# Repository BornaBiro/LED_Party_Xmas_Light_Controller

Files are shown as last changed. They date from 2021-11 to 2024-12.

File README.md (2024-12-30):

# 🎄LED Party And Xmas Light Controller🎄

ATMGEA328P based project for ccontrolling WS2801 RGB LEDs (addressable LEDs with dedicated IC controller, not the ones with built-in controller). It's primarlly used for controlling LED lights for Xmass, but with some code modification can be used for smart ambient light or even a party light (it already has dedicated mode for that, but it does not work properly, more about that later).

<p align="center">
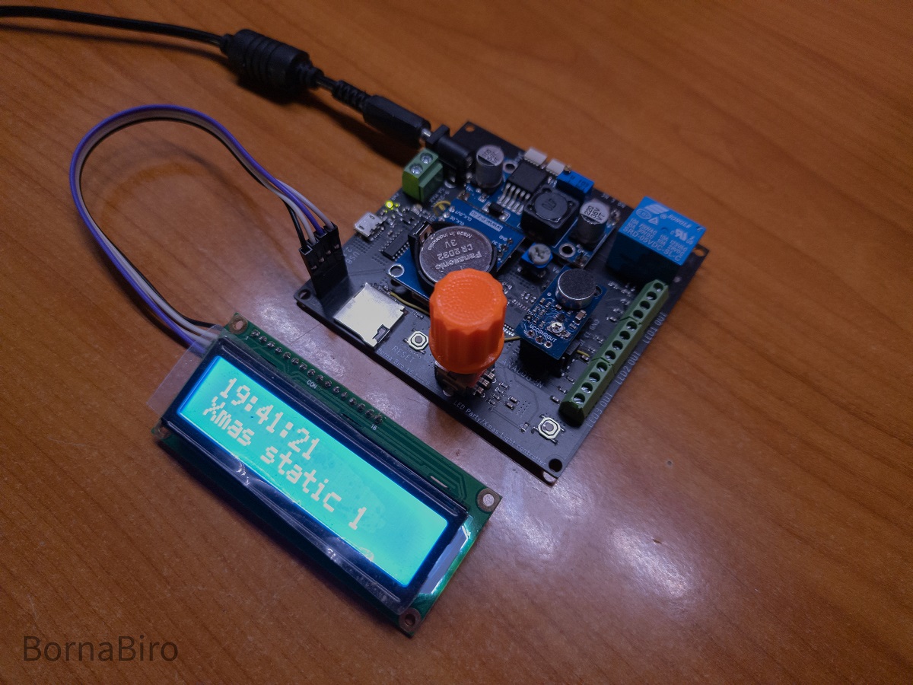
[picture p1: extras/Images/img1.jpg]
  
</p>

<p align="center">
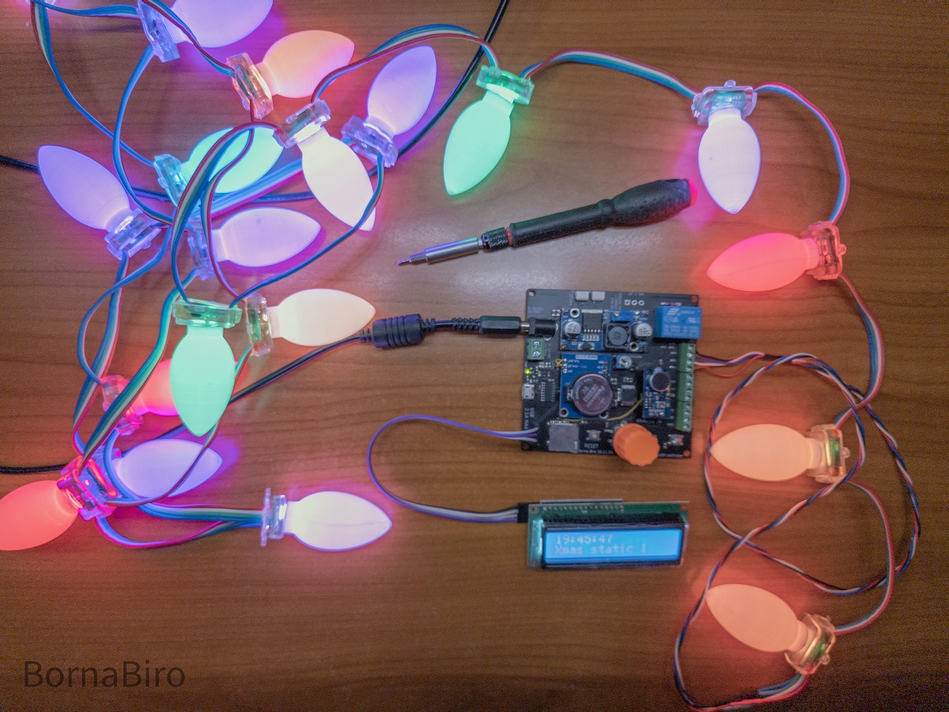
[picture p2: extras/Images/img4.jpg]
  
</p>

## Features 
- microUSB supply
- DC Jack supply (microUSB and DC Jack **CAN'T** be used at the same time!)
- Terminal block for power supply (connected in parallel with DC Jack)
- Analog audio input for MAX4466 microphone breakout
- microSD card reader
- 16x2 I2C LCD
- 2 (3) x LED Channels
- built-in buck regulator for 5V power supply
- RTC for automatic power on and off
- relay output (**for non-mains use only**)
- rotary encoder wuth pushbutton for navigating menu
- buzzer for playing old school Xmas melodies
- CH340 USB to UART IC for easy programming and debugging
- Reset pushbutton
- Addidional pushbutton
- easyC / STEMMA / Qwiic I2C connector for additional I2C devices

There is very neat little feature with this device: it creates same melodies as these old school incandescent Xmas lights. Check that out [here](https://github.com/BornaBiro/LED_Party_Xmas_Light_Controller/blob/dev/Codes/Melody%20Extract/README.md).

## Getting started 🚀
1. Get the board!
2. Get the parts!
3. Solder everything together (except DC-DC converter, **you must set the output voltage to 5V-5.2V first**)
4. Connect DC-DC converter to the power supply and set the output voltage to the 5V-5.2V
5. Solder it to the PCB using the headers
6. Burn the bootloader to the ATMEGA328P (using the test pads at bottom side of the PCB). You can use Arduino as ISP. If you don't know how to use it, check it out [here](https://docs.arduino.cc/built-in-examples/arduino-isp/ArduinoISP).
7. Copy / install provided WS2801 library to the Arduino
8. Open the sketch
9. Set Board as Arduino Nano (Arduino Nano with ATMEPGA328P, old bootloader).
10. Upload the sketch
11. Have fun!

## Contributions to this project
- [ladyM9](https://github.com/ladyM9) - Little help for the timer code (got few ideas on how to approach the problem). Thank you!
- [keith204](https://www.thingiverse.com/keith204/designs) 3D Printed caps for the LEDs - https://www.thingiverse.com/thing:3331268

## Hadrware issues
⚠️**NOTE**⚠️

Before making the CB you have to know that current version of the PCB has _some_ hardware issues. All issues are listed [here](https://github.com/BornaBiro/LED_Party_Xmas_Light_Controller/tree/dev/PCB#hadrware-issues).

⚠️**NOTE**⚠️

I **did not** fix any of these on PCB design, so like I mentioned, you will either need to do these fixes or you will need to make changes on the PCB before you order it.

## Software issues
Software is still in the progress of make it. Since I do not have much free time, do not have high hopes on fixing these. I'll try my best to fix these before Xmas and New Year.
Whole code is written to be non-blocking.

Known issues:
1. Xmas mode and Party Mode are not seperated. Actually on new and updated version only Xmas mode exists!
2. Only xmas mode is working properly
3. Be careful while setting up current Xmas mode, because you can force it into party mode by incrementing it to the Moon and beyond. Not sure if this is a bug or feature. 😆
4. No day selecton on automatic on or off (no date setting either)
5. 3D printed case is still missing.
6. For longer strands with total number of LEDs > 40 one Step Down is not enough.

## To-Do list
1. Try create two different flash images fir different modes that can be loaded into ATMEGA328P from the microSD card
2. Variable/Selectable length of LEDs per output
3. Enable or disable some effects or put them in the list
4. More effects!
5. More timer intervals
6. UART control support

## How to use it
The device has two/three WS2802 LEDs outputs. Number of LEDs per output can be configured in the [code](Codes/Arduino%20Code/led_party_xmas_light_controller/defines.h), STRAND1, STRAND2 and STRAND3. Third channel can be used for relay output (selected by default) or for one more channel for LEDs. On first start up it will set all setting to default ones. Every settting is stored in ATMEGA328P EEPROM. To enter menu, press Rotary Enc. To go thorugh menu, rotate rotary encoder. To enter settings, press the encoder again. Rotate it to set parameters. To go on the next parameter press the encoder. To exit setting, wait or simply keep pressing until `>` is not visable anymore. `>` shows what parametes is currently being set. To exit menu, wait or go to `Exit`. The menu will timeout as well as the backlight.

### Menu
  - Current mode: Shows current mode - Only Xmas for now
  - Current setting: Shows what light mode is currently active (same on the main menu along with the clock)
  - Frame speed: To slow or speed up the current animation (in percent)
  - Animation dur.: How long to keep current light effect (in seconds)
  - Auto Change: If enabled it will go though all light modes automatically.
  - Melody: If enabled it will play the melody if light mode has melody.
  - Auto Start: If set on `Auto`, light will power up automaticaly accordingly on `Activation Time` intervals. Relay and LEDs are seperated. `On` will keeps LEDs or relay on all the time overriding timer intervals.
  - Set Time: Set the time on RTC.
  - Activation Time: Set the times when the device will be powered on. First time is when device will be enabled, second is when the deivce disable LEDs/Relay. Y/N is if this timeslot it even enabled or not.
  - Exit: Exit menu.

## Few more images

<p align="center">
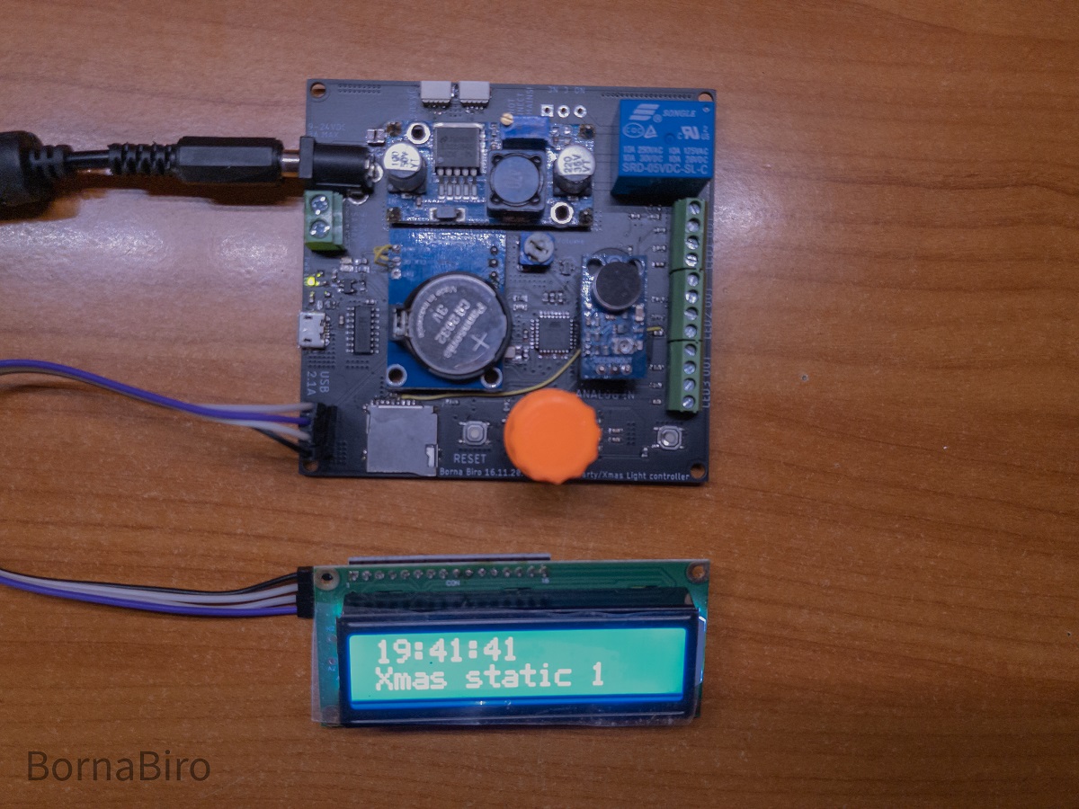
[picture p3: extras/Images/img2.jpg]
  
</p>

<p align="center">
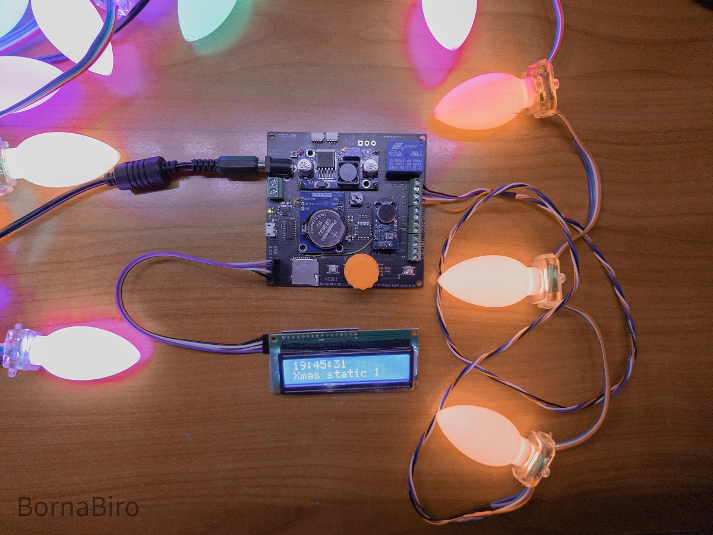
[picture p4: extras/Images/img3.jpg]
  
</p>

## Licence
This project uses MIT licence. It is provided as is - no warranty is given. In other words - use it at your own risk.
You can use this project, change it, modify it, but source must be listed (this github repo) as well as the author name.

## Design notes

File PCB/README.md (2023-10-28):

PCB CAD files are made with EAGLE. I will add gerbers files later (if needed).

### Hadrware issues
Yeah, this things happen, it doesn't work from the first try, so there are some fixes you need to make in order to your PCB work properly.

1. microUSB connector does not fit. I use wrong footprint. Used microUSB connector is [920-E52A2021S10100](https://www.lcsc.com/product-detail/USB-Connectors_Jing-Extension-of-the-Electronic-Co-920-E52A2021S10100_C10418.html)
2. Missing SMD 10uF MLCC at DC input
<p align="center">
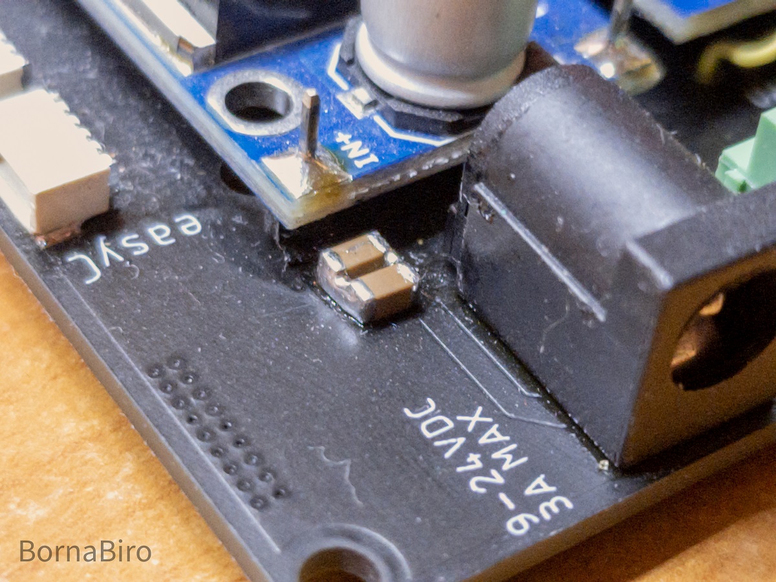
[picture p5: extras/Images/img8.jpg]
  
</p>
3. Missing debounce capacitor on rotary enncoder pushbutton from pin to GND (100nF)
<p align="center">
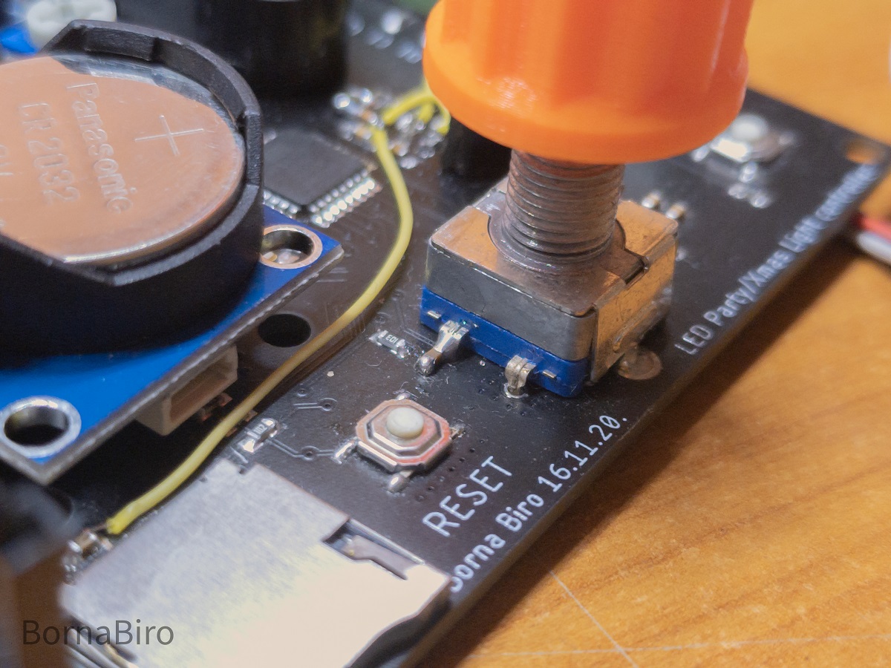
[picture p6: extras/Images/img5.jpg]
  
</p>
4. Analog audio part... Ohh boy... AVCC and AREF sholud be seperated (AVCC should be on 5V but AREF should be on 3V3), bias curcuit is missing filtering, MIC and bias must be supplied from 3V3.
<p align="center">
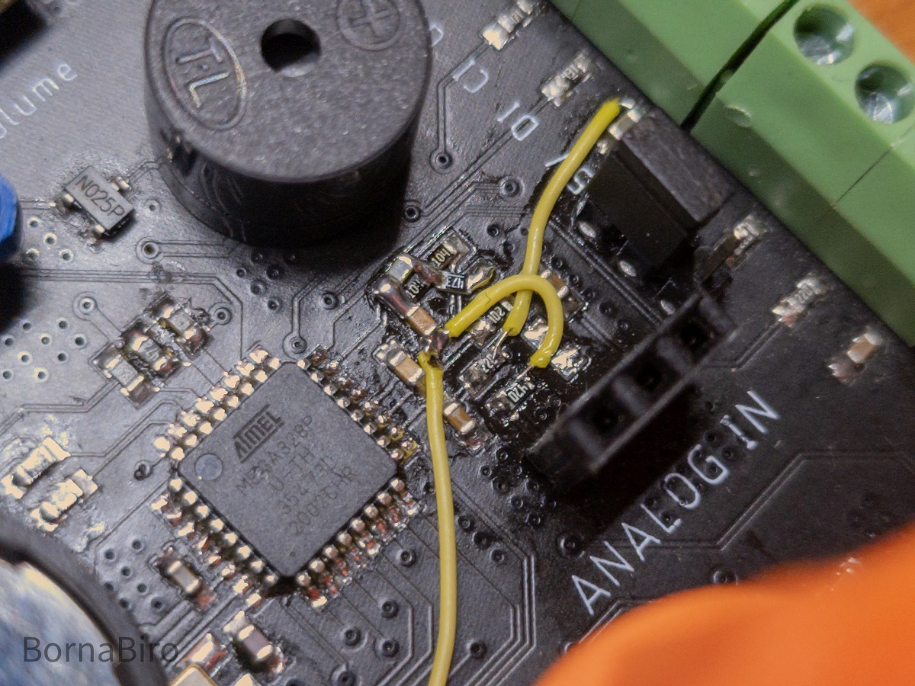
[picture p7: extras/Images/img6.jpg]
  
</p>
5. No GND at 3V3 VREG... This one hurts the most...
<p align="center">
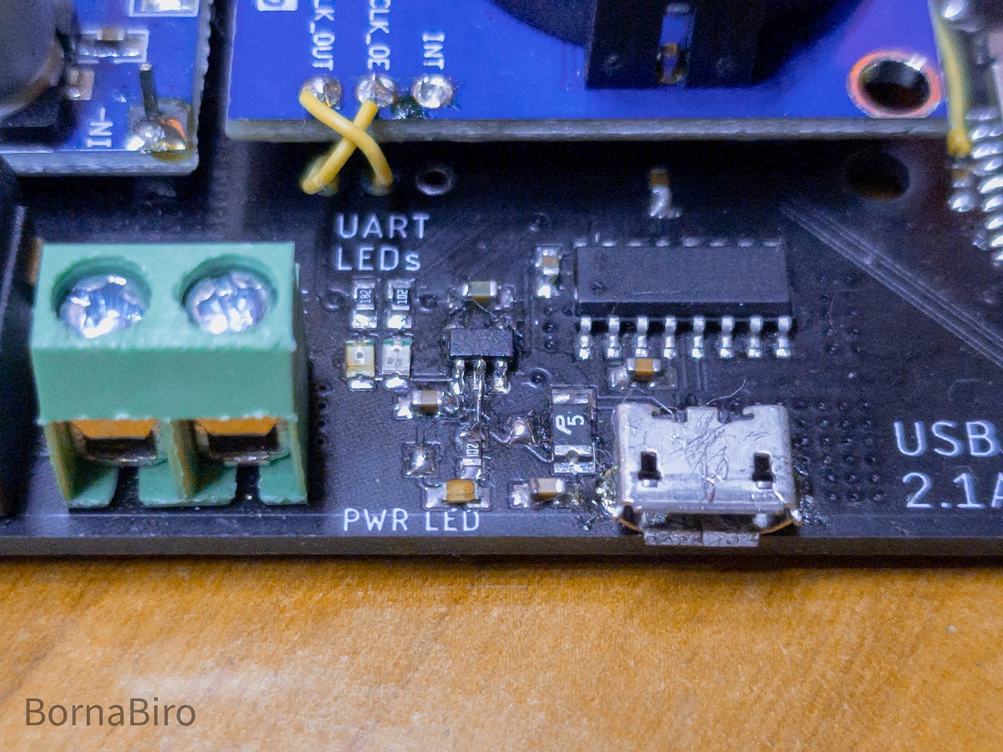
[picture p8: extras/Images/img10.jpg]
  
</p>
6. Swapped CLK_OUT and CLK_OE... and this one...
<p align="center">
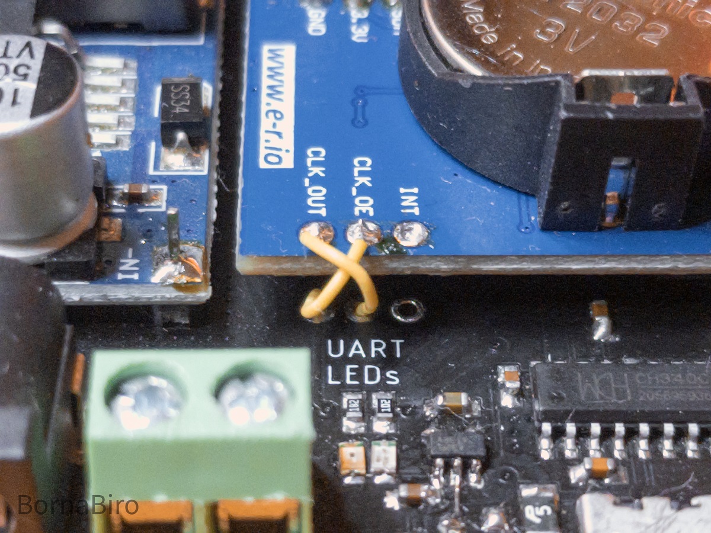
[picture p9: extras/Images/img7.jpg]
  
</p>
7. In order to make MIC breakout to work properly (so it does not capture noise from the power supply), cut the MIC supply trace and add 10uF 1206 MLCC.
<p align="center">
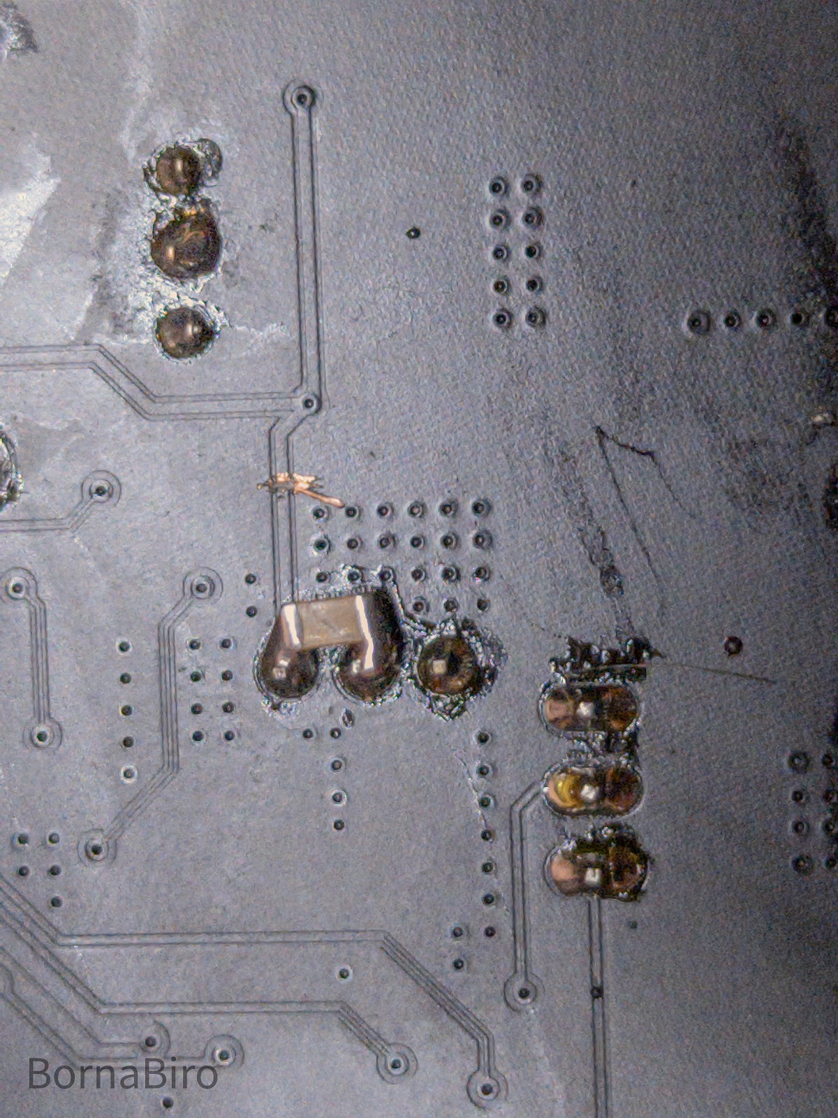
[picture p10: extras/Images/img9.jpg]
  
</p>
8. Added two 1206 10uF MLCC at the output of the DC-DC converter to reduce high frequency noise.
<p align="center">
  
</p>
9. Some of these DC-DC converters are noisy. If needed, add 470uF at the output of the DC-DC converter.

**NOTE** I did not fix any of these on PCB design, so like I mentioned, you will either need to do these fixes or you will need to make changes on the PCB before you order it.

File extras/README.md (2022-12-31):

NOTE: All there songs are extracted from old filament lamp type X-mas lights controller box. I have no idea if they are copyrighted or not, so use it only for educational, demostrantional and non-commertional use only!

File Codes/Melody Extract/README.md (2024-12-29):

# Code for melody extraction from old school Xmas light "automata"

## Intro
Remeber these things? We use to hate it back in the days with it's irritating melodies they produced. But nowdays I really miss these melodies. Maybe I'm little bit nostalgic ... or crazy, who knows. :D 
<p align="left">
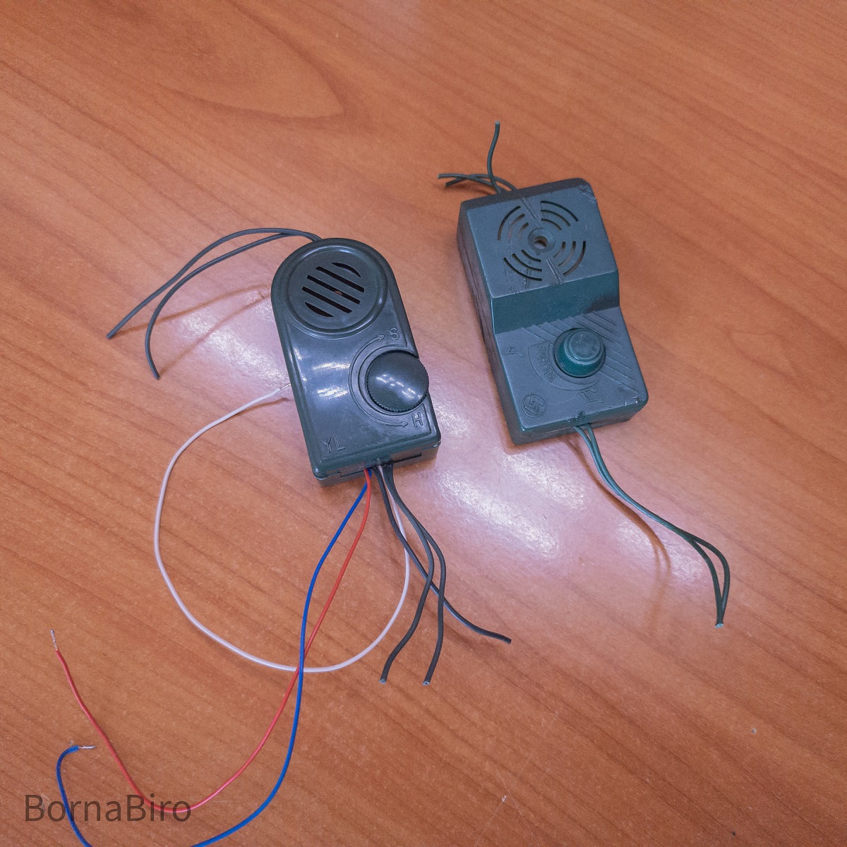
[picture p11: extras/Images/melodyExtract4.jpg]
  
</p>

I wanted to add melodies from these little noise makers, but I colud not found them anywhere on the web in the form of the notes and their durations in miliseconds.
I could find the songs and then manually convert them into notes (and frequencies) and durations, but this takes way too much time.
Or I could use these two and record the sound the produce into .wav file, store it on the microSD card and reproduce it with ATMEGA328P, but that would use way too much memory and CPU cycles.
But I needed much simpler solution. I got an idea. What if I record the signal comming from the IC inside this automata and use that?

But how? Well, here is how I done it. By using cheap 24MHz logic analyzer and some C code, of course!
<p align="left">
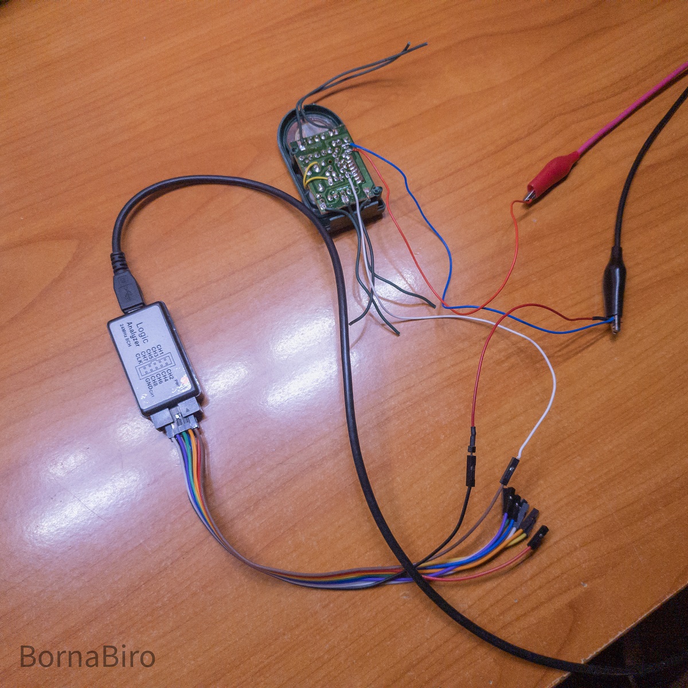
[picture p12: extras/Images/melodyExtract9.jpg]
  
</p>

You could use alerady extracted files (provided here as [newerAutomata.csv](https://raw.githubusercontent.com/BornaBiro/LED_Party_Xmas_Light_Controller/dev/Codes/Melody%20Extract/newerAutomata.csv) and [oldestAutomata.csv](https://raw.githubusercontent.com/BornaBiro/LED_Party_Xmas_Light_Controller/dev/Codes/Melody%20Extract/oldestAutomata.csv)) or even cleaned up file [here](https://raw.githubusercontent.com/BornaBiro/LED_Party_Xmas_Light_Controller/main/extras/xmas_light_automata_songs.txt).
But, if you are having one with the different set of melodies, join me on this adventure.

## Hardware side of things
First question that you may ask yourself can be "How do I connect logic analyzer to that?!" and that would be great a question. First thing to note that, what ever you do

> :warning: **DO NOT CONNECTED THEM INTO MAINS WHILE DOING ANYTHING RELATED TO THIS, PLEASE!!!**.

The truth is, these little devices run on about 3-5VDC. There is simple resistive dropper circuit that will convert 230VAC (or 120VAC) to 3-5V needed IC inside this box to create the melody.
So, for the supply, we need lab. power supply set to 3V with current limit set to no more than 30mA. But, again, where to connect this supply?!?! Calm down, it's actually very easy, just find electrolitic capacitor rated at 16V.
Usually this is the main filter capacitor. Just be careful about the polarity. If there is two caps, one is usually for the main filtering and other one is for speaker. How to know which is which is *fairly easy*; on capacitor, both legs are connected to the main IC, the one for the speaker can only hove one connected to the IC or even none (if the device has transistor ampplifier circuit).

<p align="left">
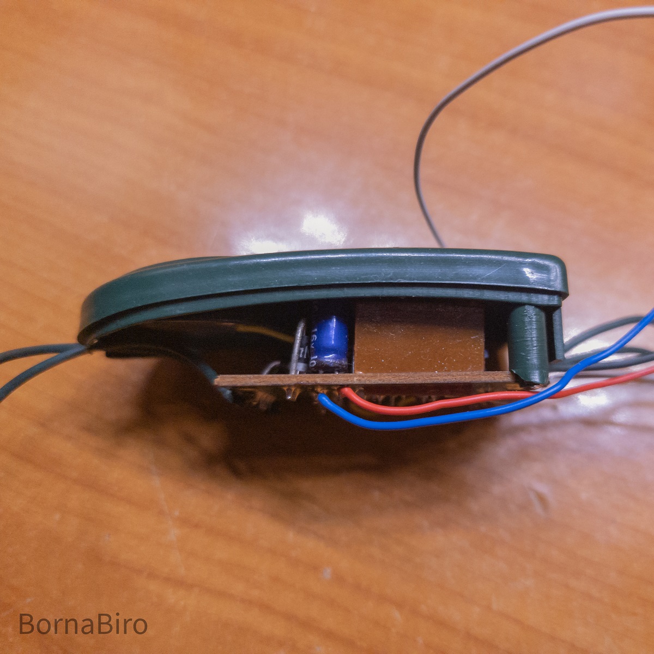
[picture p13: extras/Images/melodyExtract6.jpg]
  
</p>

Now, if you connect the supply, this little noisemaker should start producing sound. If not, either is dead or you connected it wrong. In this case, check the supply current - if needs more than 30mA check the polarity or it's wrong capacitor.

Ok, ok, but where do I connect logic analyzer? Easy there! Fisrt, you will need an oscilloscope. And this does not to be fancy one. Even kit oscilloscopres can be used for this. But for what? Well, we need to find the output pin that goes into speaker to be able to capture the signal.
To find it, power the this noisemaker (**AGAIN NOT FROM THE MAINS, BUT FROM THE LAB. POWER SUPPLY WITH 3-5VDC!**) and try to find pin that produces squarewave with the frequency of about 500Hz to 2kHz. Thats your melody! To be sure, you can attach a small speaker (like a headphones) to check if this is really a signal that we are looking for.

<p align="left">
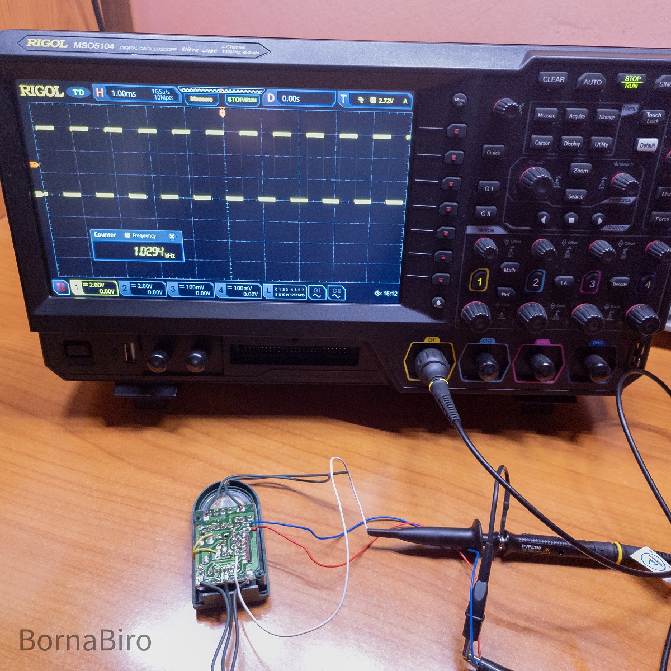
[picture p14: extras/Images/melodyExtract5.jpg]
  
</p>

I already soldered white wire to it (and again, **black nad red wires are 4VDC!**).

Here is the otherone where I'm probing it with the oscilloscope.

<p align="left">
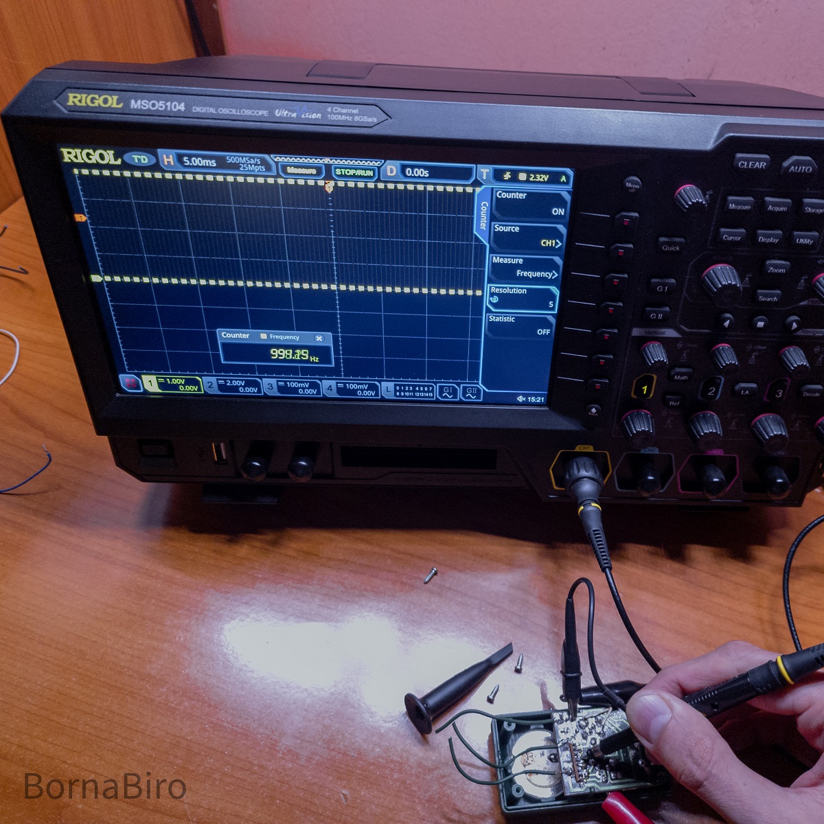
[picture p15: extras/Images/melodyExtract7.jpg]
  
</p>

Close-up shot.

<p align="left">
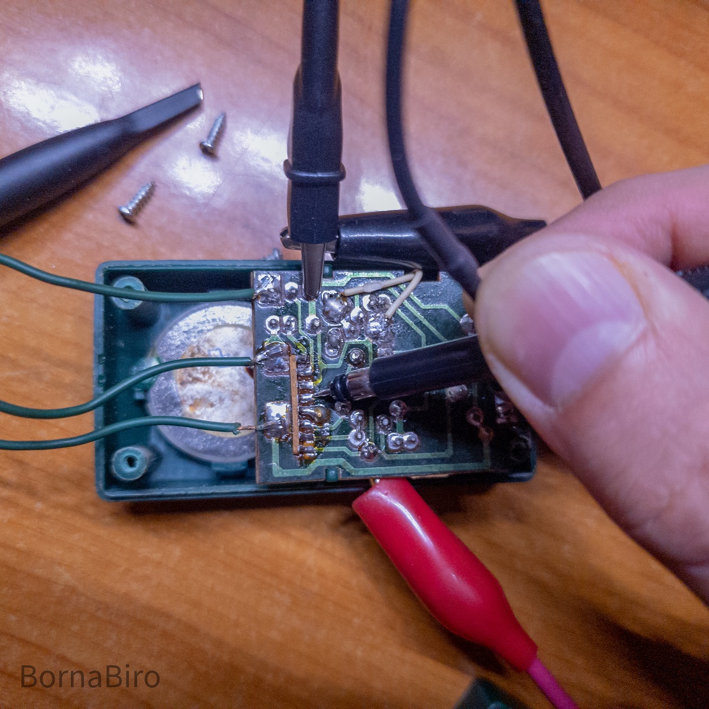
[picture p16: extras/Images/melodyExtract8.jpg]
  
</p>

As you can se this pin generates signal with 50% duty and the frequency is chaning with the sound. That's our signal! Now, solder the wire and connect it to the CH0 of the logic analyzer.

## Software side of things
Ok, now we have the signal, but how to convert that into something useful. Yea sure we can do this manually (please don't) by recording a video and than writing down frequrncies and duration seen on oscilloscope or recording a melody and setting a scopoe on slow time base and by using cursors extract frequency and duration. Or capture everything with the logic analyzer and then manually analyze frequencies and their durations. But this won't be a *engineering* method right? Besides, where is fun in that?
It's much better to write the code that will extract these values. So I did exactly that! Script can be found [here](main.cpp). The code is written in C/C++. I run it by using [DevCpp](https://www.bloodshed.net) but you can run it with simple GCC Compiler.
Code is ment to parse Salea Logic 2 .csv output with all 8 channels active.

<p align="left">
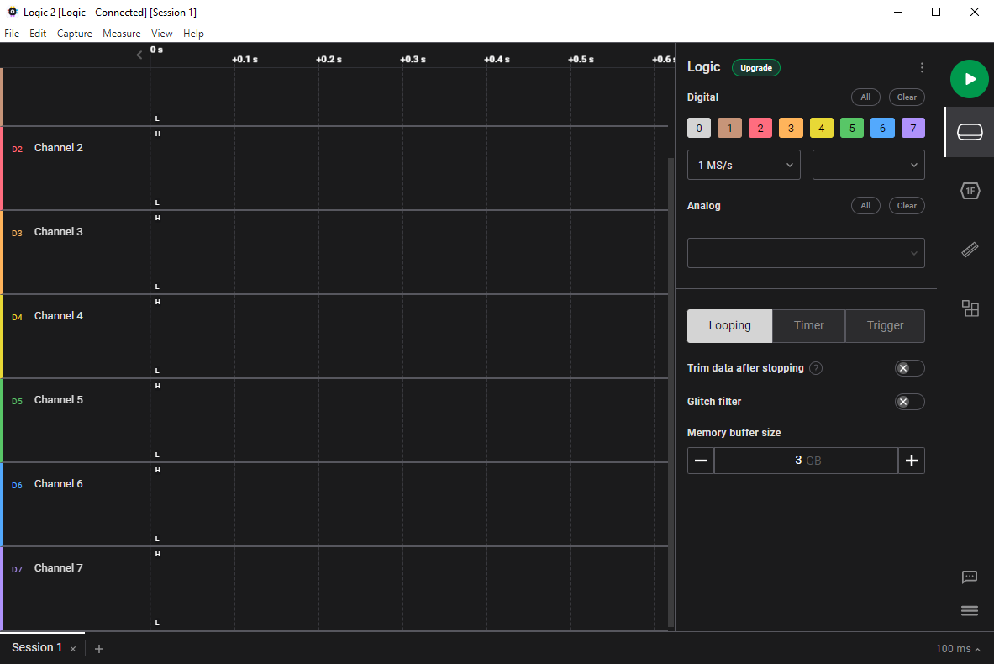
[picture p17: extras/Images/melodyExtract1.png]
  
</p>

Captured data template:
```
Time [s],Channel 0,Channel 1,Channel 2,Channel 3,Channel 4,Channel 5,Channel 6,Channel 7
```

Example of one data point.
```
0.000000000,1,1,1,1,1,1,1,1
```

For script to work properly, use only channel 0 of the logic analyzer!
For export data use this settings:
<p align="left">
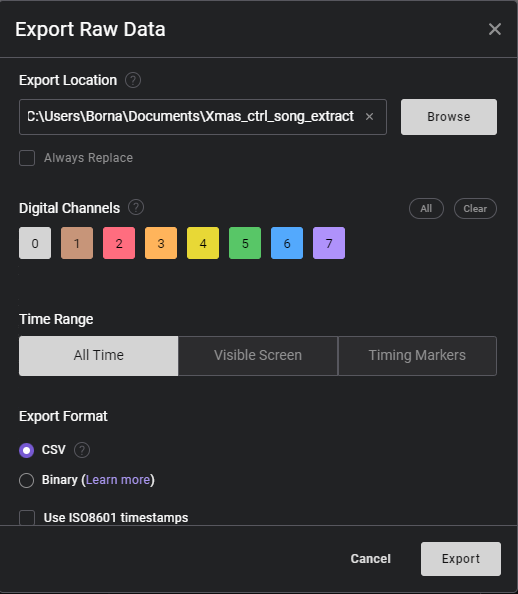
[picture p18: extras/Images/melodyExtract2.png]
  
</p>

You can use [songData.csv](songData.csv) as filename, or you can use whatever name you want as long as you change it in [main.cpp](main.cpp). After running script, you will get [output.csv](output.csv) with frequencies in Hz (Hertz) on the left and durations in milliseconds on the right.

<p align="center">
  
</p>

What the script actually doing is carefully analyzing data and watches for the pin state change and when this happens it captures time from the input time data and calculates the frequency. If frequency is changed from prevoius calculated one (plus tollerance) it save is to the file and also calculates the duration. If not it keeps reading the file until the file is read completly. Now you can use this with any MCU (in my case Arduino and ATMEGA328P).

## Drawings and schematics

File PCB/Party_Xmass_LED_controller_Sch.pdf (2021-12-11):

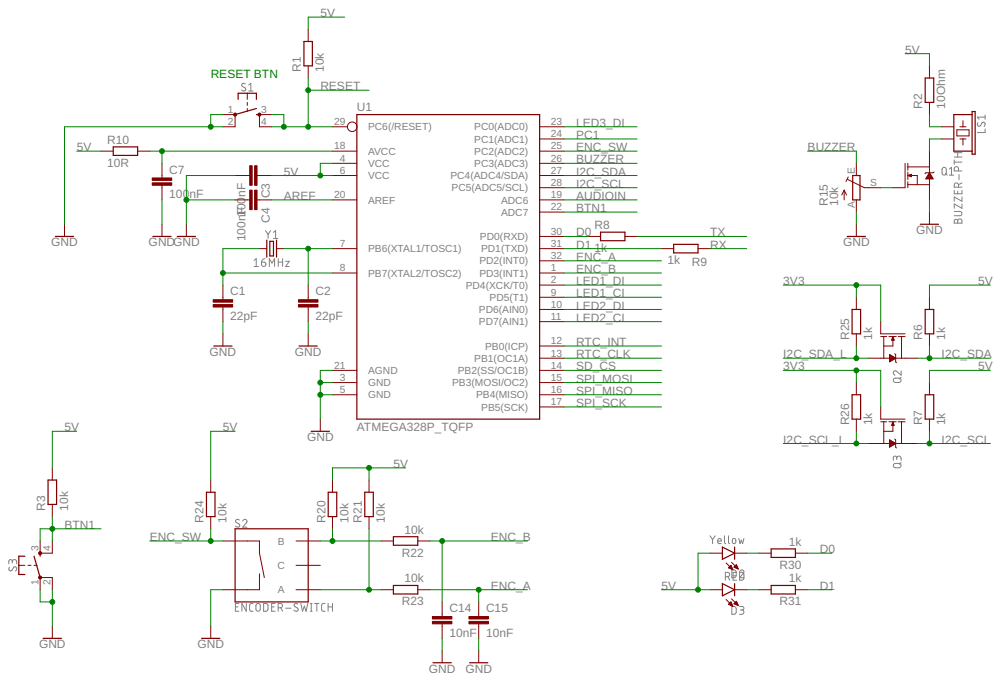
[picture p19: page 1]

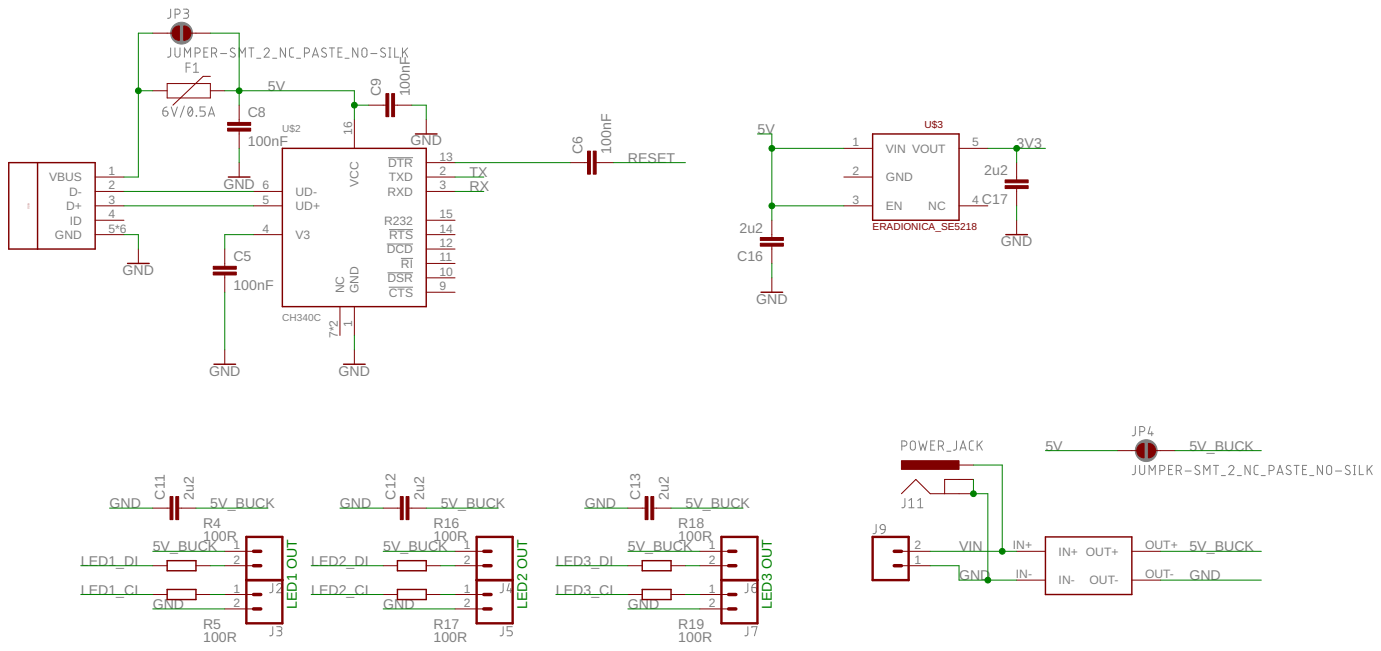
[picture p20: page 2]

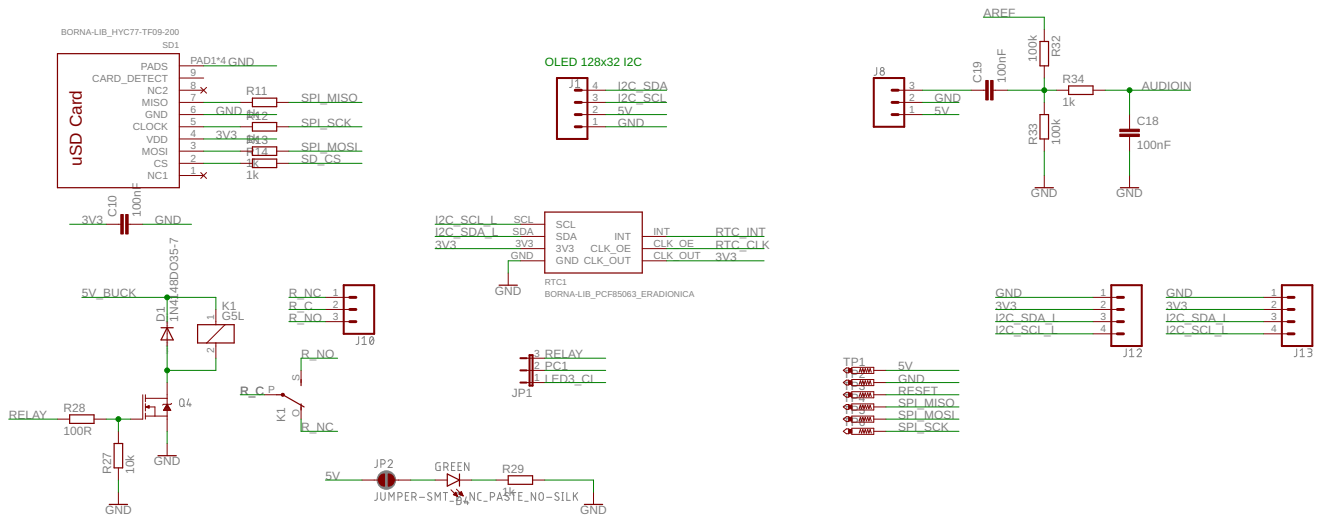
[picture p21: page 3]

SpiceOrder 1 SpiceOrder 2 BORNA-LIB_HYC77-TF09-200 1k1k1k1k 100nF GND BORNA-LIB_PCF85063_ERADIONICA 1G5L N4148DO35-7 GND 10k GND 100R 1k GND 100k 100k 1k 100nF 100nF GND GND CARD_DETECT 9 CLOCK 5 CS 2 GND 6 MISO 7 MOSI 3 NC1 1 NC2 8 PADS PAD1*4 VDD 4 SD1 R11 R12 R13 R14 C10 1234 3V3 3V3 CLK_OE CLK_OE CLK_OUT CLK_OUT GND GND INT INT SCL SCL SDA SDA RTC1 2 1 K1 O S P K1 D1 R27 R28 123 JP1 R29 R32 R33 R34 C18 123 C19 123 TP1 TP2 TP3 TP4 TP5 TP6 1234 1234 GNDGND GND GND GND GND GND GND SPI_MISO SPI_MISO SPI_SCK SPI_SCK SPI_MOSI SPI_MOSI SD_CS 3V3 3V3 3V3 3V3 3V3 3V3 RTC_INT RTC_CLK I2C_SDA_L I2C_SDA_L I2C_SDA_L I2C_SCL_L I2C_SCL_L I2C_SCL_L I2C_SDA I2C_SCL 5V 5V 5V 5V RELAY RELAY LED3_CI PC1 AUDIOIN AREF R_C R_CR_NO R_NO R_NC R_NC RESET 5V_BUCK uSD Card OLED 128x32 I2C

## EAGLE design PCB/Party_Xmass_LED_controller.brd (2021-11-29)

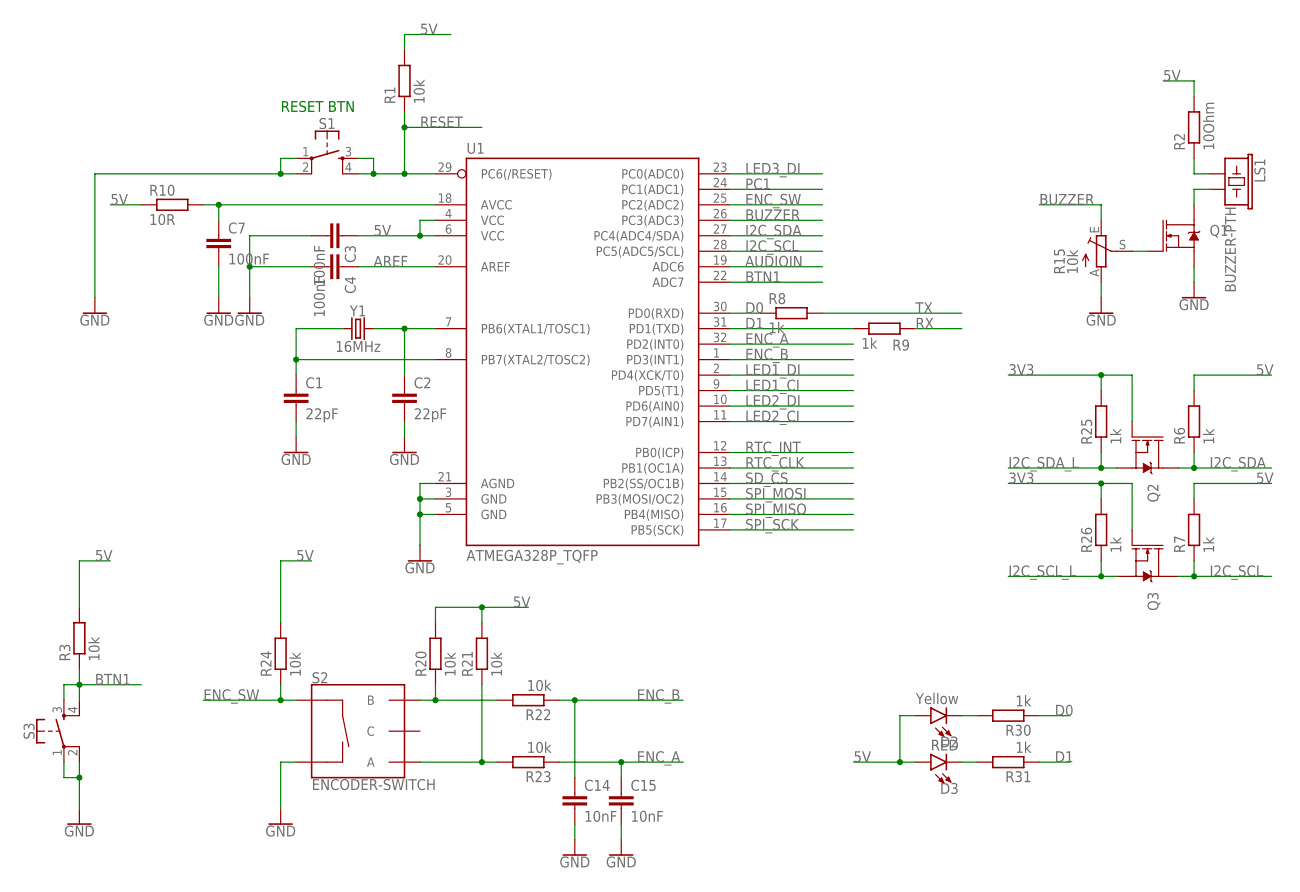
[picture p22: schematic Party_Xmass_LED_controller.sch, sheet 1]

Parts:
C1, C2: 22pF; C0603
C3, C4, C7: 100nF; C0603
C14, C15: 10nF; C0603
D2: Yellow; LED-0603
D3: RED; LED-0603
LS1: BUZZER-PTH; BUZZER-12MM
Q1, Q2, Q3: MOSFET-NCH-BSS138; SOT23-3
R1, R3, R20, R21, R22, R23, R24: 10k; R0603
R2: 10Ohm; R0603
R6, R7, R8, R9, R25, R26, R30, R31: 1k; R0603
R10: 10R; R0603
R15: 10k; CA6V
S1, S3: MOMENTARY-SWITCH-SPST-2-SMD-5.2MM; TACTILE_SWITCH_SMD_5.2MM
S2: ENCODER-SWITCH; ROTARY_ENC_PLAIN
U1: ATMEGA328P_TQFP; TQFP32-08
Y1: 16MHz; CRYSTAL-SMD-5X3.2-4PAD

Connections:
3V3: Q2.1 (G), Q3.1 (G), R25.2, R26.2; also elsewhere on the board
5V: C3.1, D2.A, D3.A, R1.2, R2.2, R3.2, R6.2, R7.2, R10.1, R20.2, R21.2, R24.2, U1.4 (VCC), U1.6 (VCC); also elsewhere on the board
AREF: C4.1, U1.20 (AREF); also elsewhere on the board
AUDIOIN: U1.19 (ADC6); also elsewhere on the board
BTN1: R3.1, S3.3, S3.4, U1.22 (ADC7)
BUZZER: R15.E, U1.26 (PC3(ADC3))
D0: R8.1, R30.1, U1.30 (PD0(RXD))
D1: R9.1, R31.1, U1.31 (PD1(TXD))
ENC_A: C15.1, R23.1, U1.32 (PD2(INT0))
ENC_B: C14.1, R22.1, U1.1 (PD3(INT1))
ENC_SW: R24.1, S2.SW+, U1.25 (PC2(ADC2))
GND: C1.2, C2.2, C3.2, C4.2, C7.2, C14.2, C15.2, Q1.2 (S), R15.A, S1.1, S1.2, S2.SW-, S3.1, S3.2, U1.3 (GND), U1.5 (GND), U1.21 (AGND); also elsewhere on the board
I2C_SCL: Q3.3 (D), R7.1, U1.28 (PC5(ADC5/SCL)); also elsewhere on the board
I2C_SCL_L: Q3.2 (S), R26.1; also elsewhere on the board
I2C_SDA: Q2.3 (D), R6.1, U1.27 (PC4(ADC4/SDA)); also elsewhere on the board
I2C_SDA_L: Q2.2 (S), R25.1; also elsewhere on the board
LED1_CI: U1.9 (PD5(T1)); also elsewhere on the board
LED1_DI: U1.2 (PD4(XCK/T0)); also elsewhere on the board
LED2_CI: U1.11 (PD7(AIN1)); also elsewhere on the board
LED2_DI: U1.10 (PD6(AIN0)); also elsewhere on the board
LED3_DI: U1.23 (PC0(ADC0)); also elsewhere on the board
unnamed: R20.1, R22.2, S2.B
unnamed: LS1.- (2), Q1.3 (D)
unnamed: LS1.+ (1), R2.1
unnamed: C2.1, U1.7 (PB6(XTAL1/TOSC1)), Y1.3 (2)
unnamed: C1.1, U1.8 (PB7(XTAL2/TOSC2)), Y1.1
unnamed: C7.1, R10.2, U1.18 (AVCC)
unnamed: R21.1, R23.2, S2.A
unnamed: Q1.1 (G), R15.S
unnamed: D2.C, R30.2
unnamed: D3.C, R31.2
PC1: U1.24 (PC1(ADC1)); also elsewhere on the board
RESET: R1.1, S1.3, S1.4, U1.29 (PC6(/RESET)); also elsewhere on the board
RTC_CLK: U1.13 (PB1(OC1A)); also elsewhere on the board
RTC_INT: U1.12 (PB0(ICP)); also elsewhere on the board
RX: R9.2; also elsewhere on the board
SD_CS: U1.14 (PB2(SS/OC1B)); also elsewhere on the board
SPI_MISO: U1.16 (PB4(MISO)); also elsewhere on the board
SPI_MOSI: U1.15 (PB3(MOSI/OC2)); also elsewhere on the board
SPI_SCK: U1.17 (PB5(SCK)); also elsewhere on the board
TX: R8.2; also elsewhere on the board

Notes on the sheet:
RESET BTN

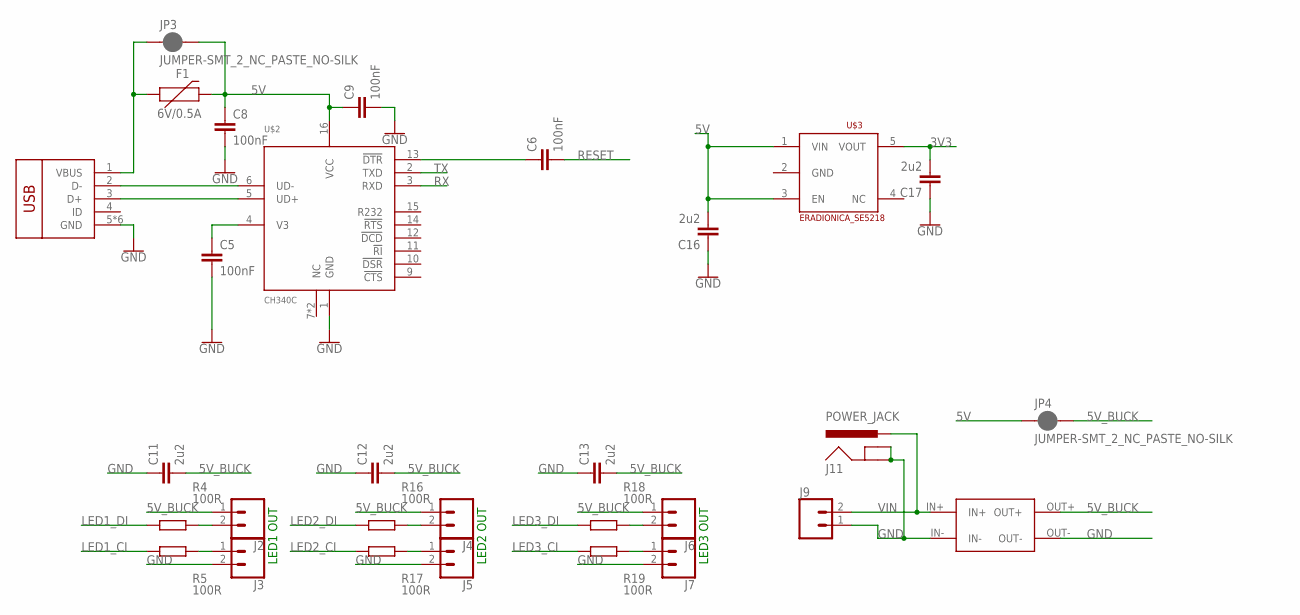
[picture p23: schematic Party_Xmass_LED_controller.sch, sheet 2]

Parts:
C5, C6, C8, C9: 100nF; C0603
C11, C12, C13, C16, C17: 2u2; C0603
F1: 6V/0.5A; 1206
J2, J3, J4, J5, J6, J7: CONN_023.5MM; SCREWTERMINAL-3.5MM-2
J9: CONN_025MM; SCREWTERMINAL-5MM-2
J11: POWER_JACK; POWER_JACK_PTH
JP3, JP4: JUMPER-SMT_2_NC_PASTE_NO-SILK; SMT-JUMPER_2_NC_PASTE_NO-SILK
R4, R5, R16, R17, R18, R19: 100R; R0603
U$1: ERADIONICA_USB-MICRO; ERADIONICA_U-F-M5DD-Y-L
U$2: CH340C; SOP-16
U$3: ERADIONICA_SE5218; ERADIONICA_SOT23-5
U$4: STEPDOWN_MODULE_LM2596

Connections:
3V3: C17.2, U$3.5 (VOUT); also elsewhere on the board
5V: C8.1, C9.1, C16.2, F1.2, JP3.2, JP4.1, U$2.16 (VCC), U$3.1 (VIN), U$3.3 (EN); also elsewhere on the board
5V_BUCK: C11.2, C12.2, C13.2, J2.1, J4.1, J6.1, JP4.2, U$4.OUT+; also elsewhere on the board
GND: C5.2, C8.2, C9.2, C11.1, C12.1, C13.1, C16.1, C17.1, J3.2, J5.2, J7.2, J9.1, J11.GND, J11.GNDBREAK, U$1.5 (GND), U$1.PAD (GND), U$1.SHIELD1 (GND), U$1.SHIELD2 (GND), U$1.SHIELD3 (GND), U$1.SHIELD4 (GND), U$2.1 (GND), U$4.IN-, U$4.OUT-; also elsewhere on the board
LED1_CI: R5.1; also elsewhere on the board
LED1_DI: R4.1; also elsewhere on the board
LED2_CI: R17.1; also elsewhere on the board
LED2_DI: R16.1; also elsewhere on the board
LED3_CI: R19.1; also elsewhere on the board
LED3_DI: R18.1; also elsewhere on the board
unnamed: C5.1, U$2.4 (V3)
unnamed: C6.1, U$2.13 (!DTR)
unnamed: U$1.2 (D-), U$2.6 (UD-)
unnamed: U$1.3 (D+), U$2.5 (UD+)
unnamed: F1.1, JP3.1, U$1.1 (VBUS)
unnamed: J2.2, R4.2
unnamed: J3.1, R5.2
unnamed: J4.2, R16.2
unnamed: J5.1, R17.2
unnamed: J6.2, R18.2
unnamed: J7.1, R19.2
RESET: C6.2; also elsewhere on the board
RX: U$2.3 (RXD); also elsewhere on the board
TX: U$2.2 (TXD); also elsewhere on the board
VIN: J9.2, J11.PWR, U$4.IN+

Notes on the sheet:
LED1 OUT
LED2 OUT
LED3 OUT

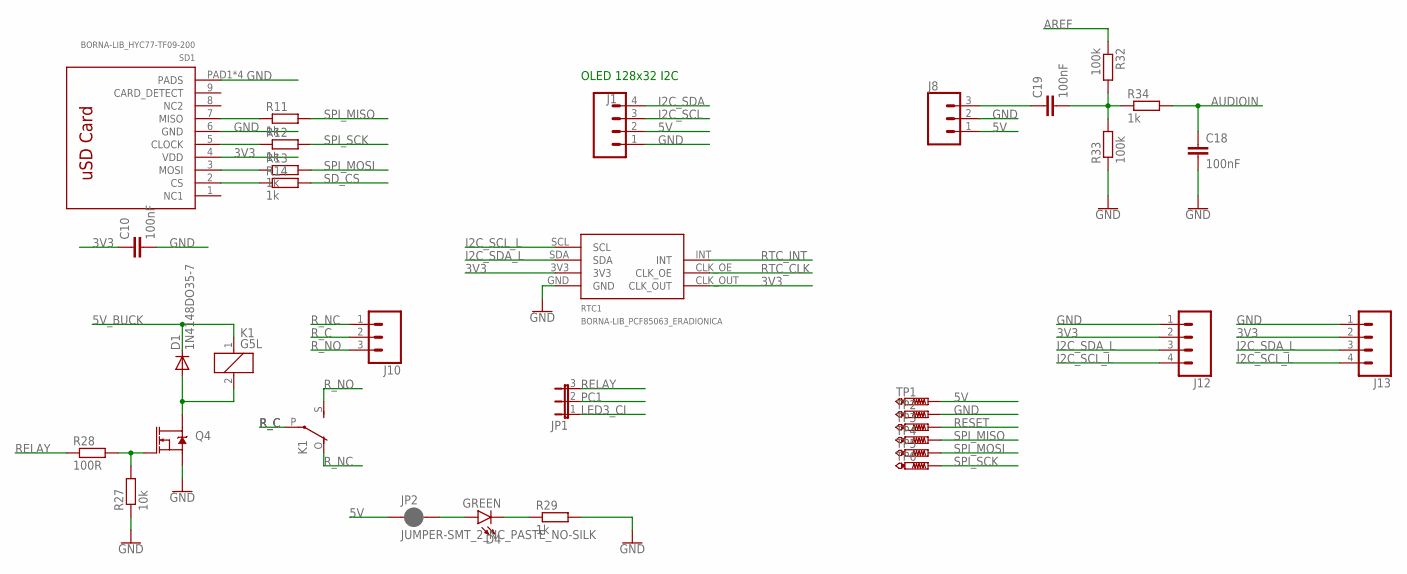
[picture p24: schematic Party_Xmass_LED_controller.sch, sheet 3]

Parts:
C10, C18, C19: 100nF; C0603
D1: 1N4148DO35-7; DO35-7
D4: GREEN; LED-0603
J1: CONN_04; 1X04
J8: CONN_03; 1X03
J10: CONN_03SCREW; SCREWTERMINAL-3.5MM-3
J12, J13: CONN_04SMD2; 1X04_1MM_RA
JP1: JP2E; JP2
JP2: JUMPER-SMT_2_NC_PASTE_NO-SILK; SMT-JUMPER_2_NC_PASTE_NO-SILK
K1: G5L; G5LE
Q4: MOSFET-NCH-BSS138; SOT23-3
R11, R12, R13, R14, R29, R34: 1k; R0603
R27: 10k; R0603
R28: 100R; R0603
R32, R33: 100k; R0603
RTC1: BORNA-LIB_PCF85063_ERADIONICA
SD1: BORNA-LIB_HYC77-TF09-200; BORNA-LIB_MICROSD_HOLDER
TP1, TP2, TP3, TP4, TP5, TP6: PTR1B1,27; B1,27

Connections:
3V3: C10.1, J12.2, J13.2, RTC1.3V3, RTC1.CLK_OUT, SD1.4 (VDD); also elsewhere on the board
5V: J1.2, J8.1, JP2.1, TP1.TP; also elsewhere on the board
5V_BUCK: D1.C, K1.1; also elsewhere on the board
AREF: R32.1; also elsewhere on the board
AUDIOIN: C18.1, R34.2; also elsewhere on the board
GND: C10.2, C18.2, J1.1, J8.2, J12.1, J13.1, Q4.2 (S), R27.1, R29.2, R33.1, RTC1.GND, SD1.6 (GND), SD1.PAD1 (PADS), SD1.PAD2 (PADS), SD1.PAD3 (PADS), SD1.PAD4 (PADS), TP2.TP; also elsewhere on the board
I2C_SCL: J1.3; also elsewhere on the board
I2C_SCL_L: J12.4, J13.4, RTC1.SCL; also elsewhere on the board
I2C_SDA: J1.4; also elsewhere on the board
I2C_SDA_L: J12.3, J13.3, RTC1.SDA; also elsewhere on the board
LED3_CI: JP1.1; also elsewhere on the board
MICIN: C19.2, R32.2, R33.2, R34.1
unnamed: C19.1, J8.3
unnamed: R11.1, SD1.7 (MISO)
unnamed: R12.1, SD1.5 (CLOCK)
unnamed: R13.1, SD1.3 (MOSI)
unnamed: R14.1, SD1.2 (CS)
unnamed: Q4.1 (G), R27.2, R28.2
unnamed: D1.A, K1.2, Q4.3 (D)
unnamed: D4.A, JP2.2
unnamed: D4.C, R29.1
PC1: JP1.2; also elsewhere on the board
RELAY: JP1.3, R28.1
RESET: TP3.TP; also elsewhere on the board
RTC_CLK: RTC1.CLK_OE; also elsewhere on the board
RTC_INT: RTC1.INT; also elsewhere on the board
R_C: J10.2, K1.P
R_NC: J10.1, K1.O
R_NO: J10.3, K1.S
SD_CS: R14.2; also elsewhere on the board
SPI_MISO: R11.2, TP4.TP; also elsewhere on the board
SPI_MOSI: R13.2, TP5.TP; also elsewhere on the board
SPI_SCK: R12.2, TP6.TP; also elsewhere on the board

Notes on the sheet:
OLED 128x32 I2C

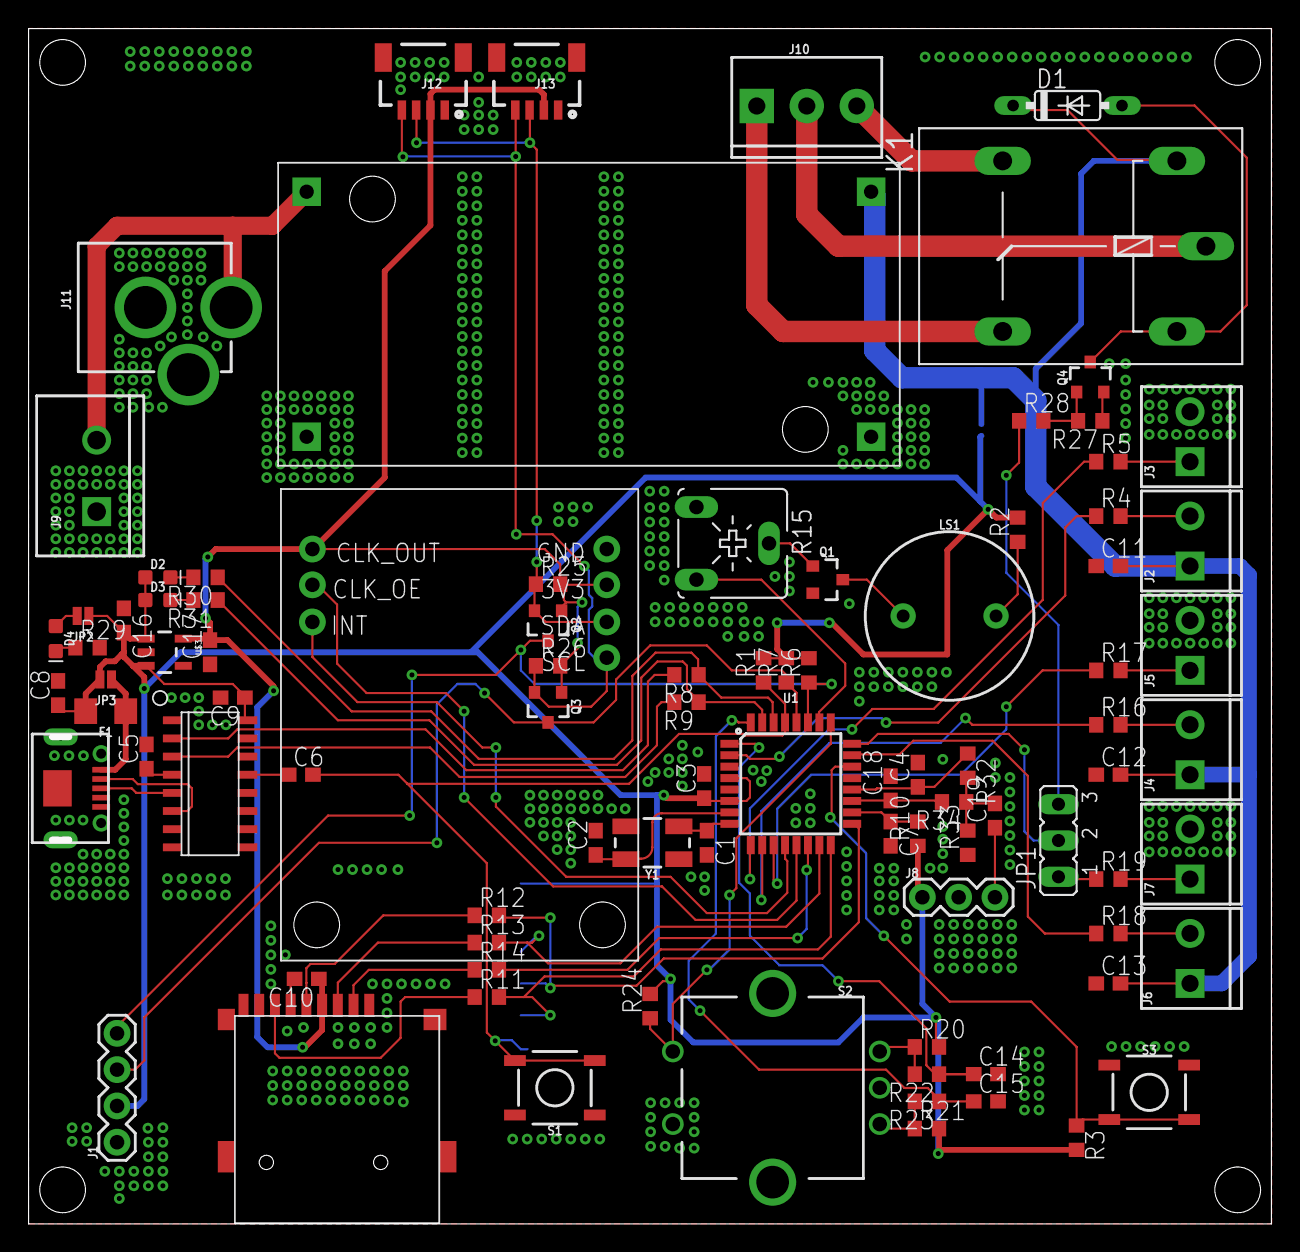
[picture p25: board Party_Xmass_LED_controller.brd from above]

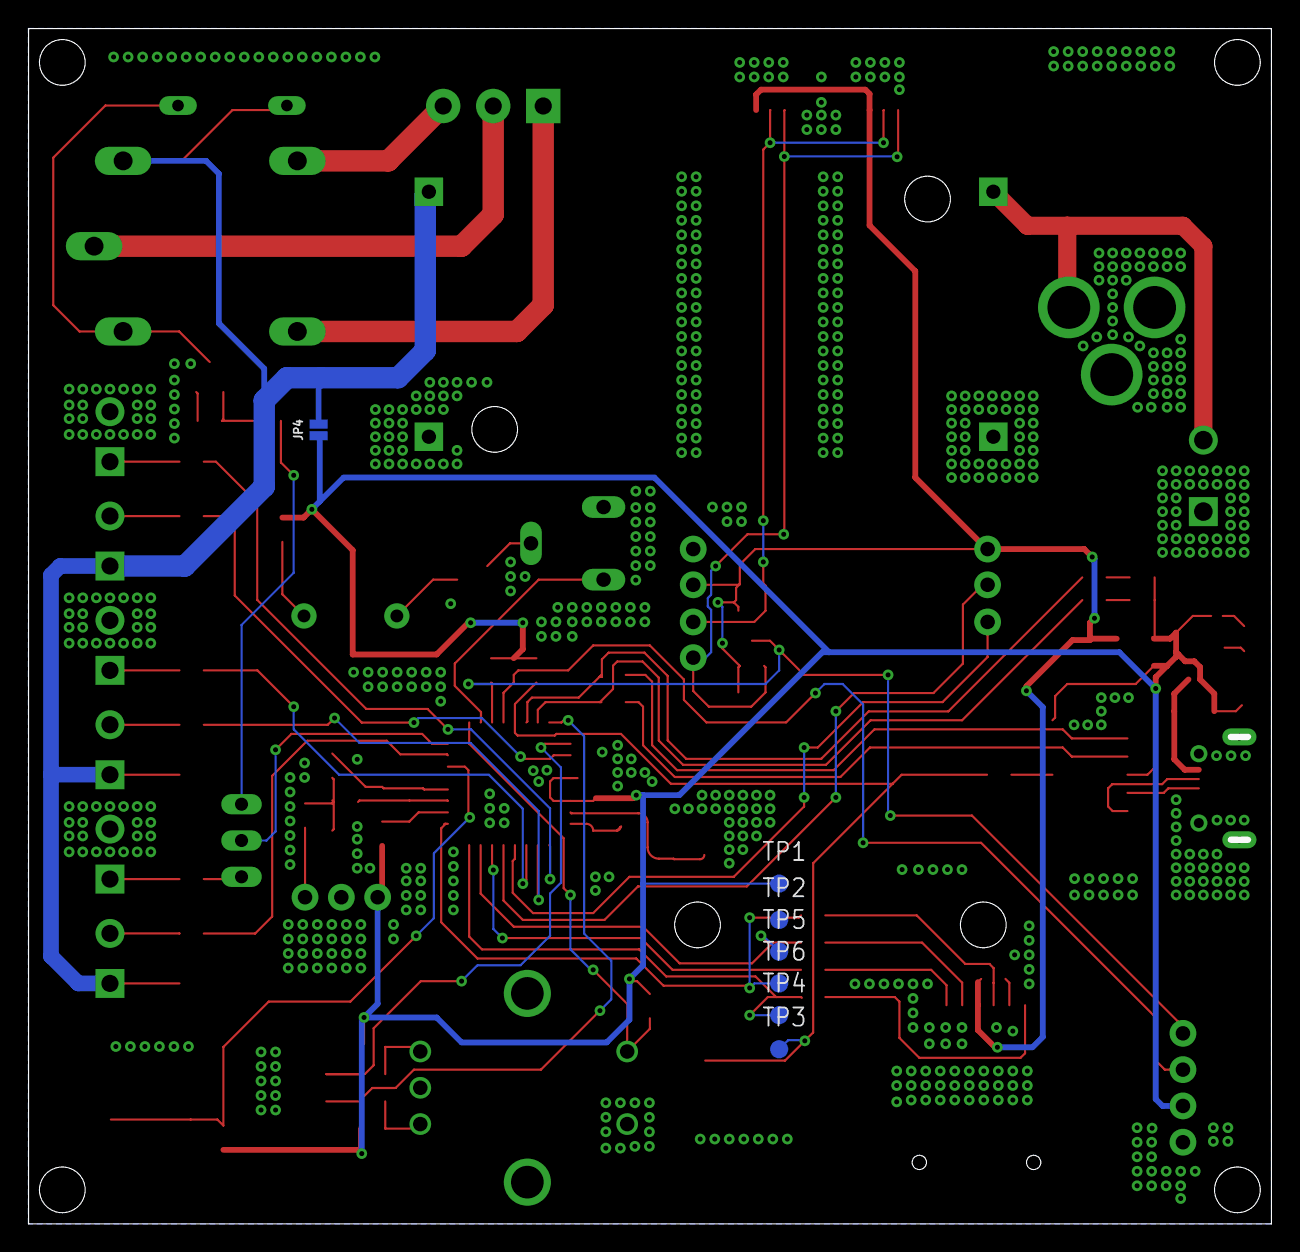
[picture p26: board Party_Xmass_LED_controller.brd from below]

Board: 2 copper layers, 87.0 x 83.6 mm, 98 parts (7 on the bottom side), 69 nets.

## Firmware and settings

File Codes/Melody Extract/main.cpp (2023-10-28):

#include <iostream>
#include "math.h"

// Old school xmas light controller song extractor.
// To use it, hook up an logic analyzer to the CH0 of yours 24MHz Logic analyzer. Other channels connect to GND.

#define FREQ_CHANGE_TOLERANCE 20

// Function define prototypes.
int skipLine(FILE *_f);
int readOneLine(FILE *_f, char *_buffer, int _bufferSize);
void printFrequency(FILE *_f, double _old, double _current, double _tolerance, double *_freqChangeTime, double _timestamp);

int main(int argc, char** argv)
{
	// Variables
	double lastTime = 0;
	double currentTime = 0;
	double lastFrequency = 0;
	double currentFrequency = 0;
	double frequencyChangeTime = 0;
	int channelData[8] = {0};
	
	// Frist open a file
	FILE *fp;
	FILE *fCsv;
	
	fp = fopen("songData.csv", "r");
	fCsv = fopen("output.csv", "w+");
	
	if (fp ==  NULL ||fCsv == NULL)
	{
		printf("Cannot open the file or create it, freezing the program!");
		return 0;
	}
	
	// File open successfully? Skip the header!
	if (skipLine(fp) != 1)
	{
		printf("Error reading the file! Stopping the program!");
		return 0;
	}
	
	// Make an buffer of one line.
	char oneLineBuffer[1000];
	
	// Now try to process all the rows of the data.
	while (readOneLine(fp, oneLineBuffer, sizeof(oneLineBuffer)))
	{
		// Get the data of the time when CH0 has changed the state.
		sscanf(oneLineBuffer, "%lf,%d,%d,%d,%d,%d,%d,%d,%d", &currentTime, &channelData[0], &channelData[1], &channelData[2], &channelData[3], &channelData[4], &channelData[5], &channelData[6], &channelData[7]);
		
		if (channelData[0] == 1)
		{
			// Calculate the freq.
			currentFrequency = 1 / (currentTime - lastTime);

			// Process it. Watchout for the frequency change. If the frequency has changed save the new frequency and save the timestamp when frequency has changed.
			printFrequency(fCsv, lastFrequency, currentFrequency, FREQ_CHANGE_TOLERANCE, &frequencyChangeTime, currentTime);
		}
		// Now current measurements are old measurements (needed for calculating the difference).
		lastFrequency = currentFrequency;
		lastTime = currentTime;
	}
	
	// Close the files.
	fclose(fp);
	fclose(fCsv);
	
	return 0;
}

int skipLine(FILE *_f)
{
	// Get the fisrt char from the line.
	char _c = fgetc(_f);
	
	// Go trough the file until you hit new line char or end of the file.
	while (_c != EOF && _c != '\n')
	{
		_c = fgetc(_f);
	}
	
	// If you hit the EOF (End of file), return an error, otherwise retrun 1 (success).
	if (_c != EOF)
	{
		return 1;
	}
	else
	{
		return 0;
	}
	
	// You should never-ever be here. If you somehow got here, throw an error.
	return 0;
}

int readOneLine(FILE *_f, char *_buffer, int _bufferSize)
{
	// Init all the variables.
	int _n = 0;
	
	// Get the first char from the line
	char _c = fgetc(_f);
	
	// Read all the chars until you hit now line or end of file, or you run out of the memory.
	while (_c != EOF && _c != '\n' && _bufferSize > 0)
	{
		_buffer[_n++] = _c;
		_c = fgetc(_f);
		_bufferSize--;
	}
	
	// Add null-trem char.	
	_buffer[_n] = '\0';
	
	// If the last chaar is EOF, return an error.
	if (_c == EOF) return 0;
	
	// Otherwise return an success!
	return 1;
}

void printFrequency(FILE *_f, double _old, double _current, double _tolerance, double *_freqChangeTime, double _timestamp)
{
	if (fabs(_current - _old) > _tolerance)
	{
		// Calulate the duration in milliseconds.
		double _duration = (_timestamp - (*_freqChangeTime)) * 1000.0;
		
		// Print all the data (for debug only)
		//printf("Frequency %lf, Duration: %lf\r\n", _current, _currentTime - (*_freqChangeTime));
		
		// Check the frequency and duration. In the duration is smaller than 100 ms or frequency is smaller than 50 Hz, ignore it.
		if (_old > 50 && _duration > 100)
		{
			// Print only frequency data.
			//printf("%d, ", (int)(_old));
		
			// Print only duration data in milliseconds.
			printf("%d, ", (int)(_duration));
			
			fprintf(_f, "%d; %d;\n", (int)(_old), (int)(_duration));
		}
		
		// If the frequency is smaller than 50 Hz, that means song has changed.
		if (_old < 50)
		{
			fprintf(_f, "\nNew song\n");
			printf("\nNew song\n");
		}
		
		*_freqChangeTime = _timestamp;
	}	
}

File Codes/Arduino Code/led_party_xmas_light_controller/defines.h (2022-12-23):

#ifndef __DEFINES_H__
#define __DEFINES_H__

// Select only one of these two
#define USE_RELAY_OUTPUT
//#define USE_WS3_OUTPUT

#if defined(USE_RELAY_OUTPUT) && defined(USE_WS3_OUTPUT)
#error "Both relay output and WS3_CLK are selected! Pick only one!"
#endif

// Sound
#define BUZZER_PIN          A3
#define BUZZER_CLICK_LEN    10UL
#define BUZZER_LONG_LEN     250UL
#define BUZZER_CLICK_FREQ   2500UL
#define AUDIO_IN A6

// Lights
#define WS1_DAT 4
#define WS1_CLK 5
#define WS2_DAT 6
#define WS2_CLK 7
#define WS3_DAT A0
#define WS3_CLK A1 // If it's used

// Number of addressable LEDs on each WS output
#define STRAND1     20
#define STRAND2     20
#define SRRAND3     20

// Inputs/Outputs
#define ENC_A      2  // It's also INT0
#define ENC_B      3  // It's also INT1
#define ENC_SW     A2 // It's also PCINT10
#define RELAY      A1 // If it's used
#define BTN_1      A7 // NOTE: It's on analog in only!
#define SD_CS      10
#define RTC_INT    8  // It's also PCINT0
#define RTC_CLKOUT 9  // It's also PCINT1

struct timerTime
{
    int8_t hoursOn;
    int8_t minutesOn;
    int8_t hoursOff;
    int8_t minutesOff;
    int8_t isEnabled;
};

struct deviceSettings
{
    int8_t currentSetting;
    int8_t currentMode;
    int16_t animationDelay;
    int8_t autoChange;
    int8_t melody;
    int8_t autoStartLeds;
    int8_t autoStartRelay;
    int16_t animationDuration;
    struct timerTime activationTimes[3];
};

const char stringEnabled[] = "Enabled";
const char stringDisabled[] = "Disabled";

#endif

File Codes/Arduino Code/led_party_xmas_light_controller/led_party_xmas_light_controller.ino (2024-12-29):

#define __AVR__

#include "Adafruit_WS2801.h"
#include "LiquidCrystal_I2C.h"
#include <SPI.h>
#include <Wire.h>
#include <EEPROM.h>

// My libs
#include "defines.h"
#include "gui.h"
#include "io.h"
#include "pcf85063.h"

// Include library fot the LED controller (animations, melody control, etc).
#include "ledController.h"

// Include library for the LED controller.
#include "melody.h"

// Include list of  the melodies.
#include "melodies.h"

// Constructors / objects
Adafruit_WS2801 led1 = Adafruit_WS2801(20, WS1_DAT, WS1_CLK);
Adafruit_WS2801 led2 = Adafruit_WS2801(30, WS2_DAT, WS2_CLK);
LiquidCrystal_I2C lcd(0x27, 16, 2);
IO io;
pcf85063 rtc;
GUI gui;

// Create LED Controller object.
LedCtrl ctrl;

// Create an object for the melody controller.
Melody melody;

void setup()
{
    // make a tone, so we know that device is alive.
    tone(BUZZER_PIN, BUZZER_CLICK_FREQ, BUZZER_LONG_LEN);
    Serial.begin(115200);
    Wire.begin();
    Wire.setWireTimeout(25000, true);

    lcd.begin(16, 2);
    lcd.clear();
    lcd.backlight();

    // Init library for the melody contoller.
    melody.begin(BUZZER_PIN, (uint16_t*)currentMelodyNotes, (uint16_t*)currentMelodyDurations, (uint8_t*)melodyElements, sizeof(melodyElements) / sizeof(melodyElements[0]));

    // Init LED controller libary.
    ctrl.begin(&led1, &led2, NULL, &melody);

    rtc.RTCinit();
    if (!rtc.isClockSet())
        rtc.setClock(1639266187);
    rtc.intOnSeconds(true);
    //rtc.setAlarm(rtc.getClock() + 15);
    //rtc.rtcInt(true);

    io.configPins();
    io.configRotaryEnc();    

    gui.init(lcd, rtc, &ctrl);

    sei();
}

void loop()
{
    int encoder = 0;
    int encoderButton = 0;

    encoderButton = io.getRotaryEncSW();
    if (io.rotaryEncAvaialble() || encoderButton)
    {
        io.getRotaryEnc(&encoder);
        gui.updateMenu(encoder, encoderButton, 0, rtc);
        gui.displayOn(lcd);
        if (!melody.isPlaying()) tone(BUZZER_PIN, BUZZER_CLICK_FREQ, BUZZER_CLICK_LEN);
    }

    gui.update(lcd, rtc);
    ctrl.update();
}

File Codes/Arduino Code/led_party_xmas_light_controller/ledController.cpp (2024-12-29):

#include "ledController.h"

// Constructor.
LedCtrl::LedCtrl()
{
    // Empty ... for now! :)
}

void LedCtrl::begin(Adafruit_WS2801 *_ledsCh1, Adafruit_WS2801 *_ledsCh2, Adafruit_WS2801 *_ledsCh3, Melody *_melodyPtr)
{
    // Copy the object addresses into local pointer array.
    _ledObjectArray[0] = _ledsCh1;
    _ledObjectArray[1] = _ledsCh2;
    _ledObjectArray[2] = _ledsCh3;

    // Copy address pointer of the melody controller locally.
    _melodyCtrlPtr = _melodyPtr;

    // Init all I/Os
    initIOPins();

    // Init typedefs.
    initFunctionPointers();

    // Set mode to the first mode.
    _currentLEDMode = 0;

    // Disable the controller.
    disable();
}

uint8_t LedCtrl::update()
{
    // Check if the LED Controlelr is enabled (if its not, there is no point in going any further).
    if (!_enabled) return;

    // Variable will hold the return value.
    // 1 = update occured.
    // 0 = no update occured.
    uint8_t _updateHappend = 0;

    if (modeList[_currentLEDMode].animation && !modeList[_currentLEDMode].melody)
    {
        // Check if the timeout has occured.
        if ((unsigned long)(millis() - _ledFrameTimer) < (unsigned long)(modeList[_currentLEDMode].animationFrameDelay * (1 + _speedOffset / 100.0))) return _updateHappend;

        // Get the new timestamp.
        _ledFrameTimer = millis();

        for (int i = 0; i < 3; i++)
        {
            // Check if the LED channel is used at all.
            if (checkLedObject(_ledObjectArray[i]))
            {
                modeList[_currentLEDMode].animationFunction(_ledObjectArray[i], &modeList[_currentLEDMode]);
            }
        }

        // Update the animation phase.
        updatePhase(&modeList[_currentLEDMode]);

        // Update the state of the return variable.
        _updateHappend = 1;
    }

    // Check if the melody also needs to be updated.
    if (modeList[_currentLEDMode].melody)
    {
        if (_melodyCtrlPtr->update())
        {
            // Update the state of the return variable.
            _updateHappend = 1;

            for (int i = 0; i < 3; i++)
            {
                // Check if the LED channel is used at all.
                if (checkLedObject(_ledObjectArray[i]))
                {
                    modeList[_currentLEDMode].animationFunction(_ledObjectArray[i], &modeList[_currentLEDMode]);
                }
            }

            // Update the animation phase.
            updatePhase(&modeList[_currentLEDMode]);
        }
    }

    // Otherwise, check if the whole mode needs to be changed (but only if automatic mode change is enabled).
    if (((unsigned long)(millis() - _modeTimeoutTimer) >= _modeTimeout) && _automaticModeUpdate)
    {
        // Capture the new time.
        _modeTimeoutTimer = millis();

        // Change the mode.
        _currentLEDMode++;

        // Check if we need to roll back to the start.
        if (_currentLEDMode >= _numberOfModes) _currentLEDMode = 0;

        // Reset the animation phase to zero.
        modeList[_currentLEDMode].animationPhase = 0;

        // Check if the animation has a melody enabled.
        if (modeList[_currentLEDMode].melody)
        {
            // Start plaing the melody.
            _melodyCtrlPtr->play();
        }
        else
        {
            // Otherwise stop the melody.
            _melodyCtrlPtr->stop();
        }

        // Force update to the LEDs.
        for (int i = 0; i < 3; i++)
        {
            // Check if the LED channel is used at all.
            if (checkLedObject(_ledObjectArray[i]))
            {
                modeList[_currentLEDMode].animationFunction(_ledObjectArray[i], &modeList[_currentLEDMode]);
            }
        }

        // Update the state of the return variable.
        _updateHappend = 1;
    }

    return _updateHappend;
}

// Disable LED controller.
void LedCtrl::disable()
{
    // If the LED controller is already disabled, return.
    //if (!_enabled) return;

    // Set the mode variable to zero.
    _enabled = 0;

    // Turn off all LEDs.
    for (int i = 0; i < 3; i++)
    {
        if (checkLedObject(_ledObjectArray[i]))
        {
            // Turn off all LEDs.
            for (int j = 0; j < _ledObjectArray[i]->numPixels(); j++)
            {
                _ledObjectArray[i]->setPixelColor(j, 0x000000);
            }

            // Send the data to them.
            _ledObjectArray[i]->show();
        }
    }
}

void LedCtrl::enable()
{
    // If the LED controller is already on, return.
    //if (_enabled) return;

    // Set enable / disable flag to 1 (enable).
    _enabled = 1;

    // Set the current animation frame to 0.
    modeList[_currentLEDMode].animationPhase = 0;

    // Get a new timestap for frames / phase and for mode timeout.
    _ledFrameTimer = millis();
    _modeTimeoutTimer = millis();

    // Force update on all LED channels.
    for (int i = 0; i < 3; i++)
    {
        if (checkLedObject(_ledObjectArray[i]))
        {
            modeList[_currentLEDMode].animationFunction(_ledObjectArray[i], &modeList[_currentLEDMode]);
        }
    }

    // Check if the animation has a melody enabled.
    if (modeList[_currentLEDMode].melody)
    {
        // Start plaing the melody.
        _melodyCtrlPtr->play();
    }
    else
    {
        // Otherwise stop the melody.
        _melodyCtrlPtr->stop();
    }

    // Increment animation phase.
    modeList[_currentLEDMode].animationPhase++;
}

uint8_t LedCtrl::getState()
{
    // Return the state of the LED Controller.
    // 1 = Enabled, 0 = Disabled.
    return _enabled;
}

void LedCtrl::setMode(int8_t _mode)
{
    // Check if the mode is valid at all.
    if ((_mode >= _numberOfModes) || (_mode < 0)) return;

    // Check if mode has changed. If the mode did not change, return.
    if (_mode == _currentLEDMode) return;

    // Save it.
    _currentLEDMode = _mode;

    // Update the LED controller.
    enable();
}

uint8_t LedCtrl::getMode()
{
    // Just return the current mode.
    return _currentLEDMode;
}

char* LedCtrl::getCurrentModeName()
{
    // Return the chart that holds the name of the current mode (but check if the ponter if not null).
    // In that case, return generic string.
    char *_modeName = modeList[_currentLEDMode].name;

    if (_modeName == NULL)
    {
        return _genericModeName;
    }

    return _modeName;
}

void LedCtrl::speedChange(int8_t _percent)
{
    // Limit to +/- 99%.
    if ((_percent > 99) || (_percent < -99)) return;

    // Save it to the internal variable. And also reverse it (positive numbers should speed up the pattern).
    _speedOffset = -_percent;

    // Also send spped change to the melody controller.
    _melodyCtrlPtr->setTempoOffset(_percent);
}

int8_t LedCtrl::getSpeed()
{
    return -_speedOffset;
}
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

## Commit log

2021-12-11 Folder structure, added LEDs reacting to audio, added library for LEDs
2021-12-11 Code for reacting LEDs to music is divided into multiple files. Added controller.h and audio.h.
2021-12-11 Do not turn on relay (for debug purpose only).
2021-12-20 Fixed audio, added multiple LED modes, added simple GUI, added LED colors
    [gui.cpp, led_party_xmas_light_controller.ino]
2021-12-21 More LED modes, added OLED screen saver, added HSV to RGB conversion, new GUI system.
2022-12-04 Many changes, creating almost new code.
    - Changed display. From 128x32 OELD to 16x2 LCD to save the memory
    - Added men: Added whole new menu code and structure
    - Fixed audio processing: Now reaction to the audio works perfectly fine.
    - Fixed RTC bug
    - Added code for the buzzer
    -
    [defines.h, gui.cpp, io.cpp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]
2022-12-19 EEPRM added, xmas songs added, fixed automatic power on/off.
    [gui.cpp, led_party_xmas_light_controller.ino]
2022-12-23 Almost finished (missing music and full party mode)
    [gui.cpp, led_party_xmas_light_controller.ino]
2022-12-23 Fixed overflow (that caused modes not to change).
    [gui.cpp]
2023-01-04 Added party mode (that broke everything)
    [gui.cpp, led_party_xmas_light_controller.ino]
2023-10-15 Switched to the external analog reference.
2023-10-28 Added script for melody extraction.
    [output.csv]
2023-12-19 Added more modes, added automatic mode change select, added one more led channel.
2023-12-21 Fixed bug in the mode settings.
    [gui.cpp]
2023-12-22 LED controller is off by default, RTC Alarm code is removed, check for the mode change.
2024-12-05 Added new effect (candles), added LCD I2C library.

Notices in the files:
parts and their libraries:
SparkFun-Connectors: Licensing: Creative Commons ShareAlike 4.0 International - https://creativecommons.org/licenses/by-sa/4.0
